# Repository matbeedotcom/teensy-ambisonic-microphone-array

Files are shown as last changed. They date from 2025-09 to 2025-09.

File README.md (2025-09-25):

# Teensy Ambisonic Microphone Array

A real-time 3D audio capture and direction-of-arrival (DOA) system using Teensy 4.1 and MEMS microphones.

## Overview

This project implements an 8-channel tetrahedral microphone array for spatial audio applications. Four INMP441 digital MEMS microphones capture sound from all directions, enabling real-time sound source localization with visual feedback.

### Key Features

- **8-channel audio capture** via dual Teensy 4.1 boards (master/slave configuration)
- **Real-time DOA estimation** using GCC-PHAT and SRP-PHAT algorithms
- **Sound classification** to filter and track specific audio types (voice, music, claps)
- **Live visualization** with 2D/3D directional plots and channel monitoring
- **3D-printable frame** with integrated wire management

## System Architecture

```
┌─────────────┐     I2S      ┌──────────────┐     USB Audio    ┌──────────────┐
│ 4x INMP441  ├─────────────►│ Master Teensy├────────────────►│              │
│ Microphones │              │     4.1      │                  │   Host PC    │
└─────────────┘              └──────┬───────┘                  │   (Python)   │
                                     │ TDM                      │              │
┌─────────────┐     I2S      ┌──────┴───────┐                  │ ┌──────────┐ │
│ 4x INMP441  ├─────────────►│ Slave Teensy │                  │ │   DOA    │ │
│ Microphones │              │     4.1      │                  │ │Processing│ │
└─────────────┘              └──────────────┘                  │ └──────────┘ │
                                                                └──────────────┘
```

## Hardware Requirements

- 2× Teensy 4.1 boards
- 8× INMP441 I2S MEMS microphone breakout boards
- 3D printer for tetrahedral frame (70.7mm edge length)
- Wire for I2S and TDM connections
- USB cables for power and data

## Quick Start

### 1. Assemble Hardware

Print the tetrahedral frame and mount microphones:
```bash
cd mechanical
python generate_stl.py  # Creates STL files for 3D printing
```

Follow the [assembly guide](mechanical/assembly_instructions.md) for wiring details.

### 2. Flash Firmware

Upload firmware to both Teensy boards:
- **Master**: `teensy_src/teensy_ambisonic_microphone.ino`
- **Slave**: `teensy_src/slave.ino`

Note: Requires [Teensyduino](https://www.pjrc.com/teensy/teensyduino.html) with USB descriptor patches from `teensy_src/patches/`.

### 3. Install Host Software

```bash
cd host_src
pip install -r requirements.txt
```

### 4. Run DOA Visualization

```bash
python doa_visualizer.py
```

Click "Start" to begin real-time sound source tracking.

## Features in Detail

### Direction of Arrival Algorithms

- **GCC-PHAT**: Fast cross-correlation for time-delay estimation
- **SRP-PHAT**: Robust beamforming-based localization
- **Least-Squares**: Traditional triangulation from time differences

### Sound Classification

Automatically identifies and filters:
- Human voice
- Music
- Claps/transients
- Whistles
- Background noise

### Array Geometry

Regular tetrahedron configuration:
- 43.3mm radius (center to vertex)
- 109.5° angular separation between microphones
- Omnidirectional coverage with minimal blind spots

## Project Structure

```
teensy_ambisonic_microphone/
├── teensy_src/        # Teensy firmware (master/slave)
├── host_src/          # Python DOA processing and visualization
├── mechanical/        # 3D-printable frame design (OpenSCAD)
└── pcb/              # KiCad PCB designs
```

## Performance

- **Sample rate**: 44.1 kHz
- **Latency**: ~23ms (1024 sample blocks)
- **Angular resolution**: 5° grid spacing
- **Update rate**: 20 Hz visualization
- **Maximum trackable distance**: Limited by SNR, typically 3-5 meters indoors

## Applications

- Acoustic scene analysis
- Smart home voice control
- Robotics navigation
- Virtual reality audio
- Acoustic research
- Educational demonstrations

## Contributing

Contributions welcome! Areas of interest:
- Multi-source tracking
- Beamforming implementation
- Raspberry Pi host support
- ROS integration

## License

MIT License - See LICENSE file for details

## Acknowledgments

Built with:
- [Teensy Audio Library](https://www.pjrc.com/teensy/td_libs_Audio.html)
- [INMP441 MEMS Microphones](https://invensense.tdk.com/products/digital/inmp441/)
- Scientific Python stack (NumPy, SciPy, Matplotlib)

## Resources

- [Direction of Arrival Estimation](https://en.wikipedia.org/wiki/Direction_of_arrival)
- [Ambisonic Audio](https://en.wikipedia.org/wiki/Ambisonics)
- [GCC-PHAT Algorithm](https://doi.org/10.1109/TASSP.1976.1162830)

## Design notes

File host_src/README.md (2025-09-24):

# Ambisonic Microphone DOA Processing

This PC application processes audio from the Teensy ambisonic microphone array to calculate and visualize sound source directions in real-time.

## Features

- **Real-time Audio Capture**: Captures multi-channel audio from Teensy USB Audio device
- **GCC-PHAT Processing**: Computes Time Difference of Arrival (TDOA) using Generalized Cross-Correlation with Phase Transform
- **DOA Estimation**: Two algorithms available:
  - **SRP-PHAT**: Steered Response Power with Phase Transform (robust in reverberant environments)
  - **Least-Squares**: Traditional triangulation method (faster computation)
- **Live Visualization**: 2D polar and 3D spherical plots showing sound source directions
- **Configurable Array Geometry**: JSON-based microphone position configuration

## Installation

1. Install Python dependencies:
```bash
pip install -r requirements.txt
```

2. Connect your Teensy ambisonic microphone array via USB

## Usage

### Quick Start
```bash
# Test audio capture
python audio_capture.py

# Test DOA processing
python doa_processing.py

# Launch visualization GUI
python doa_visualizer.py
```

### Configuration

Edit `array_geometry.json` to match your microphone array:

```json
{
  "name": "your_array_name",
  "description": "Array description",
  "positions": [
    [x1, y1, z1],
    [x2, y2, z2],
    [x3, y3, z3],
    [x4, y4, z4]
  ],
  "sample_rate": 44100,
  "speed_of_sound": 343.0
}
```

Position coordinates are in meters, relative to array center.

## File Structure

- `audio_capture.py` - USB audio interface and streaming
- `doa_processing.py` - GCC-PHAT and DOA algorithms
- `doa_visualizer.py` - Real-time visualization GUI
- `array_geometry.json` - Microphone array configuration
- `requirements.txt` - Python dependencies

## Algorithm Details

### GCC-PHAT (Generalized Cross-Correlation with Phase Transform)

1. **Windowing**: Apply Hann window to reduce spectral leakage
2. **FFT**: Compute frequency domain representations
3. **Cross-spectrum**: Calculate X₁(f) × X₂*(f) for each microphone pair
4. **PHAT Weighting**: Normalize by magnitude: C(f) / |C(f)|
5. **IFFT**: Convert back to time domain to get correlation function
6. **Peak Detection**: Find maximum within physical delay constraints

### SRP-PHAT (Steered Response Power)

1. Create spherical grid of candidate directions (5° resolution)
2. For each direction, compute expected delays between microphone pairs
3. Sample cross-correlation functions at expected delays
4. Sum contributions from all microphone pairs
5. Select direction with maximum summed response

### Least-Squares DOA

1. Extract TDOA estimates from GCC-PHAT peaks
2. Grid search over spherical directions
3. For each direction, compute expected TDOAs
4. Find direction minimizing squared error with measured TDOAs

## Performance Notes

- **Block Size**: 1024 samples provides ~23ms latency at 44.1kHz
- **Grid Resolution**: 5° spacing gives good accuracy/speed tradeoff
- **Confidence Filtering**: Helps reject spurious detections in noisy conditions
- **Memory Usage**: ~50MB typical for real-time processing

## Troubleshooting

### Audio Device Not Found
1. Check USB connection to Teensy
2. Verify Teensy appears as "Teensy Audio" or similar in device list
3. Run `audio_capture.py` to see available devices

### Poor DOA Accuracy
1. Verify microphone array geometry in `array_geometry.json`
2. Check for consistent channel mapping (clap test near each mic)
3. Adjust `speed_of_sound` for temperature: c ≈ 331 + 0.6 × T°C
4. Try larger block size (2048) in noisy environments

### High CPU Usage
1. Reduce spherical grid resolution (use 10° instead of 5°)
2. Increase block size to reduce processing rate
3. Use least-squares method instead of SRP-PHAT

## Hardware Requirements

- **Teensy 4.1** with 4-8 channel audio streaming
- **INMP441 I2S microphones** in tetrahedral or planar arrangement
- **USB connection** for audio streaming
- **PC** with Python 3.7+ and audio drivers

## Future Enhancements

- Multiple simultaneous source tracking
- Adaptive beamforming
- Noise suppression and source separation
- Integration with room correction
- Export to common audio formats

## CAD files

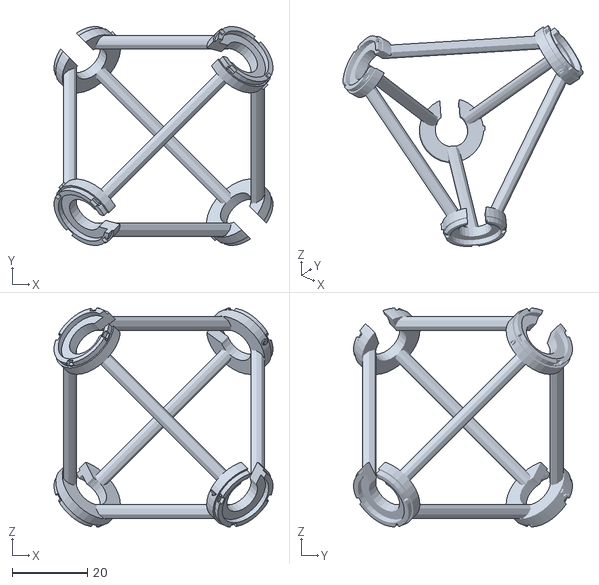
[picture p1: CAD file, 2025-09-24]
mechanical/tetrahedron_frame.stl
58.3 x 58.3 x 58.3

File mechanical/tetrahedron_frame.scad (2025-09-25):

/**
 * Tetrahedral Microphone Array Frame
 *
 * Designed for 4x INMP441 breakout boards (15mm diameter)
 * Regular tetrahedron with 50mm center-to-vertex distance
 *
 * IMPORTANT: Microphones are oriented OUTWARD from the center!
 * Each mic faces away from the tetrahedron center to capture
 * directional audio from all around the sphere.
 *
 * This gives proper ambisonic capture with sensitivity to:
 * - All horizontal directions (360° azimuth)
 * - Elevation angles from -90° to +90°
 *
 * Includes wire management and strain relief
 */

// Design parameters
vertex_distance = 25;           // Distance from center to vertex (25mm = 50mm spacing)
mic_board_diameter = 15;        // Microphone breakout board diameter
board_thickness = 1.6;          // PCB thickness
wire_diameter = 8;              // Wire bundle diameter
frame_thickness = 2;            // Frame rod thickness
mount_thickness = 3;            // Mounting pad thickness
mount_offset = -10.0;             // Distance from vertex to mounting pad (mm)
post_offset = 1.0;               // Distance from PCB edge to mounting posts (mm)
slot_rotations = [45, 90, 90, 45]; // Optimized angles for each vertex
clearance = 0.2;                // 3D printing clearance

// Calculated tetrahedron vertices (regular tetrahedron)
a = vertex_distance;
vertices = [
    [ a,  a,  a],    // Vertex 0
    [ a, -a, -a],    // Vertex 1
    [-a,  a, -a],    // Vertex 2
    [-a, -a,  a]     // Vertex 3
];

// Main assembly
module tetrahedron_frame() {
    difference() {
        union() {
            // Frame structure
            tetrahedron_edges();

            // Microphone mounting points (positioned closer to connect with frame)
            for (i = [0:3]) {
                // Calculate outward normal vector for this vertex
                normal = vertices[i] / norm(vertices[i]);
                // Position mounting pad using constant offset
                mount_position = vertices[i] + normal * mount_offset;

                translate(mount_position) {
                    // Rotate mounting surface to face outward
                    rotate([0, atan2(sqrt(normal.x*normal.x + normal.y*normal.y), normal.z), atan2(normal.y, normal.x)]) {
                        microphone_mount(i);  // Pass vertex index
                    }
                }
            }
        }

        // Wire channels through frame
        wire_channels();

        // Mounting holes for microphones (positioned closer to match mounting pad)
        for (i = [0:3]) {
            // Calculate outward normal vector for this vertex
            normal = vertices[i] / norm(vertices[i]);
            // Position mounting holes using constant offset
            mount_position = vertices[i] + normal * mount_offset;
            translate(mount_position) {
                // Rotate mounting holes to match outward orientation
                rotate([0, atan2(sqrt(normal.x*normal.x + normal.y*normal.y), normal.z), atan2(normal.y, normal.x)]) {
                    microphone_mounting_holes();
                }
            }
        }
    }

    // Labels embedded on the outside of mounting pad cylinders
    for (i = [0:3]) {
        // Calculate outward normal vector for this vertex
        normal = vertices[i] / norm(vertices[i]);
        // Position label using constant offset
        mount_position = vertices[i] + normal * mount_offset;
        translate(mount_position) {
            // Rotate label to match outward orientation
            rotate([0, atan2(sqrt(normal.x*normal.x + normal.y*normal.y), normal.z), atan2(normal.y, normal.x)]) {
                // Position label on the outside surface of the mounting pad
                rotate([0, 0, 180]) {  // Rotate to opposite side from wire slot
                    translate([0, (mic_board_diameter + 5)/2, mount_thickness/2]) {
                        rotate([90, 0, 0]) {
                            linear_extrude(1) {
                                text(str(i), size=2, halign="center", valign="center", font="Arial:style=Bold");
                            }
                        }
                    }
                }
            }
        }
    }
}

// Tetrahedron edge structure
module tetrahedron_edges() {
    difference() {
        // Connect each vertex to every other vertex (full frame)
        union() {
            for (i = [0:3]) {
                for (j = [i+1:3]) {
                    hull() {
                        translate(vertices[i]) sphere(r=frame_thickness);
                        translate(vertices[j]) sphere(r=frame_thickness);
                    }
                }
            }
        }

        // Subtract mounting pad volumes and everything above them from frame
        for (i = [0:3]) {
            // Calculate outward normal vector for this vertex
            normal = vertices[i] / norm(vertices[i]);
            // Position where mounting pad will be
            mount_position = vertices[i] + normal * mount_offset;

            translate(mount_position) {
                // Rotate to match mounting pad orientation
                rotate([0, atan2(sqrt(normal.x*normal.x + normal.y*normal.y), normal.z), atan2(normal.y, normal.x)]) {
                    // Cut out volume for mounting pad and everything above it
                    cylinder(h=50, d=mic_board_diameter + 6, center=false, $fn=32);
                }
            }
        }
    }
}

// Microphone mounting pad - fixed to frame
module microphone_mount(vertex_index = 0) {
    difference() {
        union() {
            // Base mounting pad
            cylinder(h=mount_thickness, d=mic_board_diameter + 4, center=false, $fn=32);

            // Raised rim to hold PCB (1mm thick) with snap-fit
            translate([0, 0, mount_thickness]) {
                difference() {
                    cylinder(h=1.5, d=mic_board_diameter + 3, center=false, $fn=32);
                    translate([0, 0, -0.1]) {
                        cylinder(h=1.7, d=mic_board_diameter + clearance, center=false, $fn=32);
                    }
                }
            }

            // Press-fit posts for cap attachment (4 posts)
            for (angle = [0:90:270]) {
                rotate([0, 0, angle]) {
                    translate([mic_board_diameter/2 + post_offset, 0, mount_thickness]) {
                        // Posts that the cap will press onto
                        cylinder(h=2, d=2, center=false, $fn=12);
                    }
                }
            }
        }

        // Center hole (1cm diameter) - through entire mount
        translate([0, 0, -0.1]) {
            cylinder(h=mount_thickness + 2, d=10, center=false, $fn=24);
        }

        // Cable passthrough slot - positioned to avoid frame connections
        // Rotate the slot direction based on vertex to avoid frame edge interference
        rotate([0, 0, slot_rotations[vertex_index]]) {
            translate([0, (mic_board_diameter + 6)/4, mount_thickness/2]) {
                cube([6, (mic_board_diameter + 6)/2, mount_thickness + 4], center=true);
            }
        }
    }
}

// This module is no longer needed - holes are integrated into microphone_mount()
module microphone_mounting_holes() {
    // No additional holes needed - everything is handled in microphone_mount()
}

// Central hub for wire management
module central_hub() {
    sphere(r=8, $fn=32);
}

// Wire routing channels
module wire_channels() {
    // Channels from each vertex to center
    for (i = [0:3]) {
        hull() {
            translate(vertices[i]) {
                cylinder(h=mount_thickness + 1, d=wire_diameter + 1, center=true, $fn=16);
            }
            cylinder(h=6, d=wire_diameter + 1, center=true, $fn=16);
        }
    }

    // Central wire exit hole
    cylinder(h=20, d=8, center=true, $fn=16);
}

// Removed strain relief clips - not needed

// Assembly instructions marker
module assembly_marker(vertex_num) {
    translate([0, 0, mount_thickness + 0.1]) {
        color("red") {
            linear_extrude(0.3) {
                difference() {
                    circle(d=4, $fn=16);
                    text(str(vertex_num), size=2, halign="center", valign="center");
                }
            }
        }
    }
}

// Press-fit cap for securing PCB to mounting pad
module mounting_cap() {
    difference() {
        union() {
            // Main cap body
            cylinder(h=1, d=mic_board_diameter + 2, center=false, $fn=32);

            // Raised edge to hold PCB down
            translate([0, 0, 1]) {
                difference() {
                    cylinder(h=0.5, d=mic_board_diameter + 2, center=false, $fn=32);
                    translate([0, 0, -0.1]) {
                        cylinder(h=0.7, d=mic_board_diameter - 2, center=false, $fn=32);
                    }
                }
            }
        }
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

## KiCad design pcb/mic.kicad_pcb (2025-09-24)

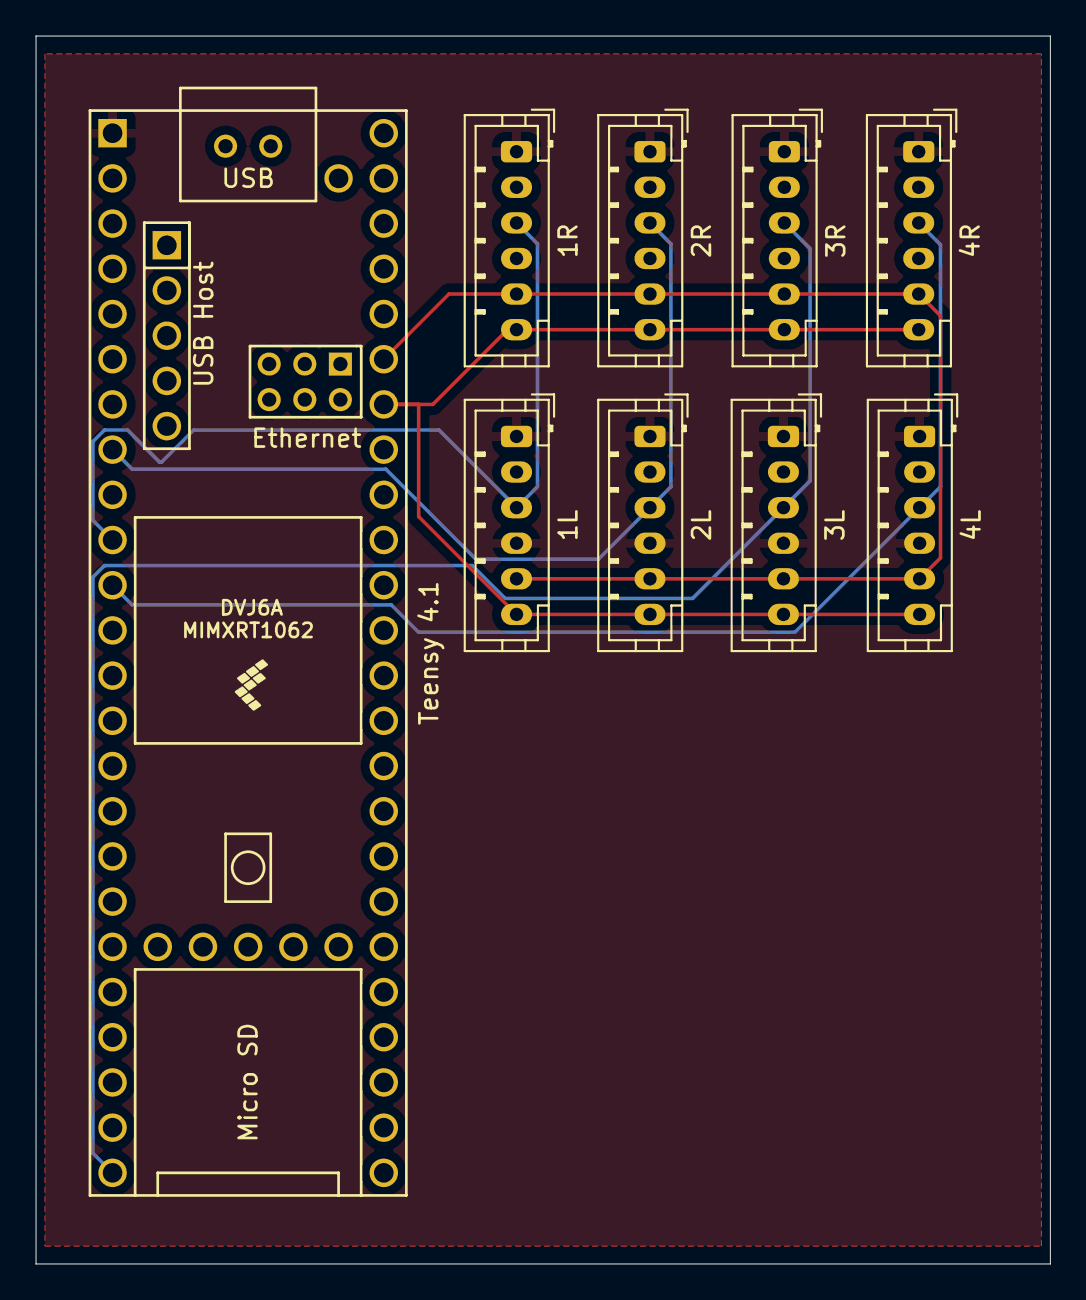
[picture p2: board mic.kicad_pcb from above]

Board: 4 copper layers, 57.0 x 69.0 mm, 9 parts (0 on the bottom side), 8 nets.

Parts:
1L, 2L, 3L, 4L: LeftMic; JST_PH_B6B-PH-K_1x06_P2.00mm_Vertical
1R, 2R, 3R, 4R: RightMic; JST_PH_B6B-PH-K_1x06_P2.00mm_Vertical
Teensy 4.1: Teensy4.1; Teensy41

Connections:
+3.3V: 1L.2, 1R.2, 1R.4, 2L.2, 2R.2, 2R.4, 3L.2, 3R.2, 3R.4, 4L.2, 4R.2, 4R.4, Teensy 4.1.46 (3V3)
BCLK1: 1L.5, 1R.5, 2L.5, 2R.5, 3L.5, 3R.5, 4L.5, 4R.5, Teensy 4.1.43 (21_A7_RX5_BCLK1)
GND: 1L.1, 1L.4, 1R.1, 2L.1, 2L.4, 2R.1, 3L.1, 3L.4, 3R.1, 4L.1, 4L.4, 4R.1, Teensy 4.1.1 (GND)
LRCLK1: 1L.6, 1R.6, 2L.6, 2R.6, 3L.6, 3R.6, 4L.6, 4R.6, Teensy 4.1.42 (20_A6_TX5_LRCLK1)
SAI1_RXD0: 1L.3, 1R.3, Teensy 4.1.10 (8_TX2_IN1)
SAI1_RXD1: 2L.3, 2R.3, Teensy 4.1.8 (6_OUT1D)
SAI1_RXD2: 3L.3, 3R.3, Teensy 4.1.24 (32_OUT1B)
SAI1_RXD3: 4L.3, 4R.3, Teensy 4.1.11 (9_OUT1C)

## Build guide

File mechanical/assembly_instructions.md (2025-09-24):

# Tetrahedral Microphone Array Assembly Instructions

## Overview
This guide covers assembly of the 3D printed tetrahedral frame for your 4-microphone ambisonic array.

⚠️ **CRITICAL**: Microphones must face **OUTWARD** from the center for proper directional audio capture!

## Parts Required

### 3D Printed Components
- [x] 1x Tetrahedral frame (`tetrahedron_frame.stl`)
- [x] 4x PCB adapter rings with twist-lock tabs (included in print)
- [x] 4x Strain relief clips (included in print)
- [x] 1x Wire management clip (included in print)

### Electronic Components
- [x] 4x INMP441 I2S microphone breakout boards (15mm diameter, 1mm thick)
- [x] 4x sets of I2S wires (5-wire: VDD, GND, SCK, WS, SD)
- [x] Small amount of double-sided tape or adhesive (optional)

### Tools Needed
- Wire strippers
- Soldering iron & solder
- Heat shrink tubing (optional)
- Small drill bit (2-3mm) for cable routing if needed

## Assembly Steps

### Step 1: 3D Print Preparation
1. **Print Settings**:
   - Layer Height: 0.2mm
   - Infill: 20-30%
   - No supports needed (designed support-free)
   - Print with central hub at bottom

2. **Post-Processing**:
   - Remove any support material or brim
   - Test-fit microphone boards in mounting holes
   - Clean mounting holes with small drill bit if needed

### Step 2: Microphone Orientation Check

**CRITICAL**: Each microphone must face **OUTWARD** from the tetrahedron center.

The INMP441 microphone element (small black square) should point:
- **Mic 0**: Up-Right-Forward direction
- **Mic 1**: Up-Left-Back direction
- **Mic 2**: Down-Right-Back direction
- **Mic 3**: Down-Left-Forward direction

### Step 3: Wire Preparation

For each microphone, prepare a 4-wire cable (~20cm length):
- **Red**: VDD (3.3V)
- **Black**: GND
- **Blue**: SCK (Serial Clock)
- **Green**: WS (Word Select/LRCLK)
- **Yellow**: SD (Serial Data)

1. Strip wire ends (~3mm)
2. Pre-tin wire ends with solder
3. Add strain relief clips to wire bundles

### Step 4: Microphone Mounting

For each of the 4 vertex positions:

1. **Orient the microphone correctly**:
   - Place breakout board on mounting pad
   - Ensure microphone element faces OUTWARD from center
   - The mic should point away from the central hub

2. **Solder connections**:
   - Solder 5-wire bundle to breakout board
   - Use heat shrink or tape for strain relief

3. **Secure with screws**:
   - Insert M2 screws through mounting holes
   - Tighten gently (don't over-torque plastic)

4. **Route wires**:
   - Thread wire bundle through vertex channel toward center
   - Leave enough slack for movement

### Step 5: Wire Management

1. **Route all wires to central hub**
2. **Group by function**:
   - All VDD wires → single power connection
   - All GND wires → single ground connection
   - Each SCK/WS/SD → separate I2S connections

3. **Use wire management clip** to organize cable bundle
4. **Add strain relief** at central hub exit

### Step 6: Testing & Calibration

1. **Visual inspection**:
   - All 4 microphones face outward ✓
   - No loose connections ✓
   - Wires properly managed ✓

2. **Electrical test**:
   - Check continuity of all connections
   - Verify no shorts between power rails

3. **Functional test**:
   - Connect to Teensy and run audio capture
   - Clap near each microphone to verify channel mapping
   - Use DOA visualizer to check directional response

## Microphone Channel Mapping

Based on your array geometry configuration:

| Position | Vertex | Direction Vector | I2S Connection |
|---|---|---|---|
| Mic 0 | (+,+,+)| Up-Right-Forward | SAI1_RXD0 Left |
| Mic 1 | (+,-,-)| Up-Left-Back | SAI1_RXD0 Right|
| Mic 2 | (-,+,-)| Down-Right-Back  | SAI1_RXD1 Left |
| Mic 3 | (-,-,+)| Down-Left-Forward| SAI1_RXD1 Right|

## Troubleshooting

### Poor Directional Response
- **Check**: Are all mics facing outward?
- **Fix**: Remount any inward-facing microphones

### Noisy Audio
- **Check**: Wire shielding and grounding
- **Fix**: Add twisted pair wiring, star ground connection

### Inconsistent Channel Levels
- **Check**: Loose connections, damaged microphones
- **Fix**: Resolder connections, replace faulty mics

### Mechanical Issues
- **Check**: 3D print quality, screw tightness
- **Fix**: Reprint damaged parts, adjust mounting

## Mounting the Complete Array

The assembled array can be mounted using:
1. **Tripod mount**: Add 1/4"-20 threaded insert to central hub
2. **Ceiling mount**: Suspend from central point with wire/chain
3. **Desktop stand**: Create weighted base with central mount point

## Final Notes

- Keep the array away from reflective surfaces during testing
- The frame is designed to minimize acoustic shadowing
- Label each microphone channel for easy identification
- Store in protective case when not in use

Good luck with your ambisonic array build! 🎤🔊

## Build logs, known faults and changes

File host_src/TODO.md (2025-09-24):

Awesome—here’s a tight, technical blueprint to get **Stage A (4-mic GCC-PHAT DOA)** working end-to-end with your Teensy and Windows host.

---

# 1) Hardware & wiring (4 mics)

Use **two I²S stereo pairs** on **SAI1**:

* Shared to all 4 mics: **BCLK = pin 21**, **LRCLK/WS = pin 20**, **3V3**, **GND** (0.1 µF at each mic).
* **Pair A** → **SAI1\_RXD0 (pin 8)**

  * Mic A-L: L/R → **GND** (Left slot), SD tied to RXD0
  * Mic A-R: L/R → **3V3** (Right slot), SD tied to RXD0
* **Pair B** → **SAI1\_RXD1 (pin 6)**

  * Mic B-L: L/R → **GND** (Left slot), SD tied to RXD1
  * Mic B-R: L/R → **3V3** (Right slot), SD tied to RXD1

Keep BCLK/LRCLK short & clean; series 22–33 Ω at the Teensy end are nice to have if wires are long.

---

# 2) Teensy firmware (capture 4 channels → USB)

* **USB Type:** Audio (16-bit, 44.1 kHz default)
* **Input:** `AudioInputI2SQuad` (uses SAI1\_RXD0 + RXD1 → 4 channels)
* **Output:** `AudioOutputUSB` (exposes 4 inputs to host)
* **Descriptor:** you already patched 4-in; if not, use the 4-ch descriptor we made.

Minimal sketch:

```cpp
#include <Audio.h>
#include <Arduino.h>

AudioInputI2SQuad i2sQuadIn;  // 4-ch on SAI1 RXD0/RXD1
AudioOutputUSB    usb_out;

// Route 4 ADC lanes -> USB in ch0..3
AudioConnection c0(i2sQuadIn, 0, usb_out, 0); // A-L
AudioConnection c1(i2sQuadIn, 1, usb_out, 1); // A-R
AudioConnection c2(i2sQuadIn, 2, usb_out, 2); // B-L
AudioConnection c3(i2sQuadIn, 3, usb_out, 3); // B-R

void setup() { AudioMemory(120); }
void loop() {}
```

**Channel order sanity:** clap near each mic and watch which host channel spikes (label them now).

---

# 3) Array geometry (choose one)

* **Tetrahedron (recommended for 3D DOA):** vertices of a regular tetra scaled to your shell. Example (meters, centered at origin):

  ```
  p0 = (  a,  a,  a)
  p1 = (  a, -a, -a)
  p2 = (-a,  a, -a)
  p3 = (-a, -a,  a)
  a = 0.025  // ~50 mm spacing tip-to-origin
  ```
* **Planar square (good for 2D azimuth):** 4 corners in one plane; you’ll estimate azimuth only (elevation ambiguous).

Store `P = [p0..p3]` in a JSON the host loads.

---

# 4) Host pipeline (GCC-PHAT → DOA)

We’ll run **block-wise**, e.g. **N=1024** samples (@44.1 kHz → ≈23 ms latency). Steps:

### (a) Read multichannel block

Get 4-ch interleaved **int16** from the Teensy USB device.

### (b) Preprocess

* Convert to float, apply Hann window.
* Optional 1st-order HPF (30–50 Hz) to remove DC/rumble.

### (c) GCC-PHAT (pairwise cross-correlation)

For each pair (i,j), compute time delay of arrival (TDOA) $\hat{\tau}_{ij}$:

1. FFT: $X_i = \mathrm{FFT}(x_i)$, $X_j = \mathrm{FFT}(x_j)$
2. Cross-spectrum: $C_{ij} = X_i \cdot \overline{X_j}$
3. PHAT weight: $C_{ij} \leftarrow C_{ij} / (|C_{ij}|+\epsilon)$
4. IFFT: $r_{ij} = \mathrm{IFFT}(C_{ij})$
5. **Peak** at allowed lags: $\hat{\tau}_{ij} = \arg\max_{|\tau| \le \tau_\text{max}} r_{ij}(\tau)$

Lag bound: $\tau_\text{max} = \frac{d_\text{max}}{c}$, $c \approx 343\,\mathrm{m/s}$, $d_\text{max}$ = max mic spacing (e.g., 0.07 m → ≈0.2 ms → ±9 samples @44.1 k).

### (d) DOA solve

#### 2D (square, azimuth only)

* Assume source on the array plane (z=0); unit direction $\mathbf{s}=[\cos\theta, \sin\theta, 0]$.
* For each pair, model $\tau_{ij} = \frac{1}{c}\,\mathbf{s}\cdot(\mathbf{p}_i - \mathbf{p}_j)$.
* **Grid search** θ ∈ \[−180°,180°], pick θ maximizing consistency with $\hat{\tau}_{ij}$ (least-squares or correlation).

#### 3D (tetra, full DOA)

Two robust approaches:

* **Least-squares on sphere:** find unit $\mathbf{s}$ minimizing
  $\sum_{i<j} \left(\hat{\tau}_{ij} - \frac{1}{c}\,\mathbf{s}\cdot(\mathbf{p}_i-\mathbf{p}_j)\right)^2$ with $\|\mathbf{s}\|=1$. Solve by coarse **spherical grid** (e.g., 5°) then local refine (Gauss-Newton) with unit-norm constraint.

* **SRP-PHAT (steered response):** create a direction grid on the sphere (3–5°). For each direction $\mathbf{s}$, convert to expected **sample delays** $d_{ij} = \mathrm{round}\big((f_s/c)\,\mathbf{s}\cdot(\mathbf{p}_i-\mathbf{p}_j)\big)$. **Sum** the cross-correlations at those delays over all pairs; pick the max.

For 4 mics, both are fast and accurate. SRP-PHAT is very robust in reverb; LS is lighter.

---

# 5) Reference host code (Python, minimal SRP-PHAT)

Below is a compact script outline (uses `sounddevice`, `numpy`). It:

* captures 4-ch blocks from Teensy,
* computes **PHAT-weighted cross-correlations**,
* evaluates a **3D grid**,
* prints azimuth/elevation.

```python
import numpy as np, sounddevice as sd
from numpy.fft import rfft, irfft
from math import pi

# -------- Config --------
fs = 44100
N  = 1024                      # block size
eps = 1e-12
c   = 343.0

# Mic positions (meters): regular tetra around origin
a = 0.025
P = np.array([[ a,  a,  a],
              [ a, -a, -a],
              [-a,  a, -a],
              [-a, -a,  a]], dtype=np.float64)
pairs = [(i,j) for i in range(4) for j in range(i+1,4)]

# Precompute a spherical grid (5°)
def sphere_grid(step_deg=5):
    dirs=[]
    for el in np.radians(np.arange(-85, 86, step_deg)):   # avoid exact poles in coarse grid
        for az in np.radians(np.arange(-180, 180, step_deg)):
            ce, se = np.cos(el), np.sin(el)
            ca, sa = np.cos(az), np.sin(az)
            dirs.append([ce*ca, ce*sa, se])
    return np.array(dirs, dtype=np.float64)
G = sphere_grid(5)             # (Ng,3)
Ng = G.shape[0]
# Expected sample delays per pair and grid dir
D = {}
scale = fs / c
for (i,j) in pairs:
    v = (P[i]-P[j]) @ G.T      # (Ng,)
    D[(i,j)] = np.rint(scale * v).astype(int)

# Choose Teensy device
dev = None
for i,d in enumerate(sd.query_devices()):
    if 'teensy' in d['name'].lower() and d['max_input_channels']>=4:
        dev=i; break
assert dev is not None, "Teensy 4-ch device not found"

# -------- Streaming loop --------
with sd.InputStream(device=dev, channels=4, samplerate=fs, blocksize=N, dtype='int16') as st:
    win = np.hanning(N).astype(np.float64)
    while True:
        x, _ = st.read(N)                 # shape (N,4), int16
        X = (x.astype(np.float64) * win[:,None])  # window & float
        # FFT along time
        XF = rfft(X, axis=0)              # (Nf, 4)

        # Pairwise PHAT cross-corr via IFFT
        score = np.zeros(Ng, dtype=np.float64)
        for (i,j) in pairs:
            Cij = XF[:,i] * np.conj(XF[:,j])
            Cij /= (np.abs(Cij) + eps)
            rij = irfft(Cij)              # circular corr, length N
            # Use a small lag window around 0 (based on array span)
            # Here: +/- 10 samples
            # Accumulate SRP by sampling rij at expected delays for each direction
            di = D[(i,j)]
            # wrap indices to [0,N)
            idx = (di % N)
            score += rij[idx]

        k = int(np.argmax(score))
        s = G[k]                           # unit DOA vector
        az = np.degrees(np.arctan2(s[1], s[0]))
        el = np.degrees(np.arcsin(s[2]))
        print(f"DOA ~ az {az:6.1f}°, el {el:5.1f}° (conf {score[k]:.2f})")
```

**Notes:**

* For a small array (≤10 cm), **±10–15 samples** is a safe lag bound—tighten for speed/robustness.
* You can refine DOA by doing a **local fine search** (1–2° step) around the coarse max.

---

# 6) Calibration & checks

* **Channel map:** do a single-mic tap test (or a beeper) near each sensor to confirm labels.
* **Geometry scale:** if DOA biases, your mic spacing may be off—measure and update `P`.
* **Speed of sound:** set `c` from ambient temp (e.g., $c \approx 331 + 0.6T_{°C}$).

---

# 7) Performance tips

* If the GCC peaks look broad/noisy, bump to **N=2048** (≈46 ms).
* **16-bit** is fine for DOA—phase dominates.
* For reverberant rooms, SRP-PHAT (as coded) outperforms simple TDOA triangulation.

---

## Milestone checklist (Stage A)

1. Teensy enumerates as **4-in**; Audacity/ffmpeg sees 4 channels.
2. Python script prints **sensible az/el** while you move a clap/snap around.
3. Save a few WAVs for offline analysis & parameter tuning.

When Stage A feels solid, we’ll bump to **8** and **12** with the same host code—just update `P` and the device’s channel count.

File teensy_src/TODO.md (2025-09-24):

Here’s the practical, nuts-and-bolts way to make **Teensy B** a **clock-slave** that **packs \~8 input channels into a single TDM stream** and sends that to **Teensy A**.

---

# 1) Wiring (one clock domain from A)

**A (master)** → **B (slave)**

* **BCLK**: A pin **21** → B pin **21**
* **LRCLK/FS**: A pin **20** → B pin **20**
* **GND**: common ground
* **TDM data B→A**: B pin **7** (`SAI1_TXD0`) → A pin **8** (`SAI1_RXD0`)

**B’s microphones** (unchanged):

* All INMP441 mics on B still use **BCLK=21** and **LRCLK=20** (now driven by A), and their **SD** lines go to B’s **RXDx** pins (e.g., SAI1\_RXD0/1/2/3 & SAI2\_RXD0/1).

---

# 2) What the firmware needs to do on Teensy B

### Inputs (mic capture) — run as **slave**

* Use the **slave** variants for I²S where available:

  * `AudioInputI2Sslave` (for a stereo pair on SAI2, etc.)
* For `AudioInputI2SQuad` (SAI1 RXD0+RXD1) there isn’t an official slave object; you either:

  * use two `AudioInputI2Sslave` objects on the lanes you’re using, **or**
  * drop in a tiny **Quad-Slave** class (I can supply this if you want to keep quad).

Either way, the key is: **B never drives clocks**; it just samples on A’s BCLK/LRCLK.

### Output (TDM transmit) — run TDM **TX as slave**

* Stock `AudioOutputTDM` configures SAI **as master**.
* For your topology, you want a **TDM TX “slave”**: SAI1 TX uses **external BCLK/LRCLK** from A and only drives **TXD0** (pin 7).

This is a very small init tweak to the TDM TX config:

* **Bit-clock direction** = **external** (SAI uses incoming BCLK)
* **Frame-sync direction** = **external** (uses incoming LRCLK/FS)
* **Frame size** = **16 slots** (we’ll use 8 of them and zero the rest)
* **Slot width** = **32 bits** (common & simple; matches Teensy’s TDM class)
* **DMA** fills the 16 slots each audio block; your 8 channels map to **slots 0–7**

---

# 3) Channel plan (8-out TDM16)

* Map your 8 captured mic channels to **TDM slots 0..7**
* Write **zeros** into slots **8..15**
* On Teensy A, use `AudioInputTDM` and read channels 0..7 (ignore 8..15)

---

# 4) Minimal code shape on Teensy B

Below is the **shape** (not the whole Teensy Audio class), so you see what changes. If you like, I can drop a ready-to-compile `AudioOutputTDM_Slave.cpp/.h` next.

```cpp
// Teensy B (slave): capture 8 mics, pack into TDM16 TX (slave), send to A

#include <Audio.h>
#include <Arduino.h>

// ---- inputs (examples) ----
// SAI1 lanes (quad) -> if you have a Quad-Slave class, use it; otherwise 2x I2Sslave
AudioInputI2Sslave i2s1_lane0; // e.g., RXD0 (Left/Right)
AudioInputI2Sslave i2s1_lane1; // e.g., RXD1 (Left/Right)

// SAI2 lane (extra stereo), optional
AudioInputI2Sslave i2s2_lane0;

// ---- TDM slave TX (custom object; uses external BCLK/LRCLK on pins 21/20) ----
AudioOutputTDM_Slave tdmTX;  // drives SAI1_TXD0 (pin 7), 16 slots/frame

// Connect 8 channels into TDM slots 0..7
// (Each AudioOutputTDM* exposes 16 inputs, like the stock TDM object.)
AudioConnection c0(i2s1_lane0, 0, tdmTX, 0);  // ch0 -> slot0
AudioConnection c1(i2s1_lane0, 1, tdmTX, 1);  // ch1 -> slot1
AudioConnection c2(i2s1_lane1, 0, tdmTX, 2);  // ch2 -> slot2
AudioConnection c3(i2s1_lane1, 1, tdmTX, 3);  // ch3 -> slot3
AudioConnection c4(i2s2_lane0, 0, tdmTX, 4);  // ch4 -> slot4
AudioConnection c5(i2s2_lane0, 1, tdmTX, 5);  // ch5 -> slot5
// Add two more inputs as needed:
AudioConnection c6(/* your next input */, 0, tdmTX, 6);
AudioConnection c7(/* your next input */, 0, tdmTX, 7);

void setup() {
  AudioMemory(200);

  // IMPORTANT: ensure B is not generating clocks
  // Using *slave* input objects does this for RX.
  // For TDM TX, our AudioOutputTDM_Slave init will configure SAI1 TX to use external BCLK/LRCLK.
}

void loop() {
  // Nothing; Audio library + DMA do the work
}
```

---

# 5) What the **TDM TX “slave” init** actually does (under the hood)

(For the i.MX RT1062 SAI, simplified; exact bit names vary slightly by header)

* **Select TDM mode / slot format**

  * `TCR4.FRSZ = 16-1`   // 16 slots per frame
  * `TCR4.SYWD = 32-1`   // 32-bit slot width
  * `TCR4.FSE = 1`       // frame sync early (aligns with standard TDM)
* **Use external clocks**

  * `TCR2.BCD = 0`       // Bit Clock Direction = external (slave)
  * `TCR4.FSD = 0`       // Frame Sync Direction = external (slave)
  * `TCR2.MSEL = 0`      // Bit-clock source = bus clock (ignored as slave)
* **Enable the transmitter on channel 0**

  * `TCR3.TCE = (1<<0)`  // Enable TX channel 0 (TXD0)
* **DMA**

  * Configure DMA to feed the TX FIFO every audio block; buffer layout = 16 interleaved slots × 32-bit words

That’s exactly what a small `AudioOutputTDM_Slave` class would set in its `begin()` before enabling `TCSR.TE`.

---

# 6) On Teensy A (the receiver)

* Keep A as **master** for clocks (default in Teensy Audio lib).
* Add `AudioInputTDM tdmIn;` and wire your 12 local + 8 remote channels as needed.
* A’s pin **8** is `SAI1_RXD0` → that’s the TDM data from B.
* USB on A advertises **(local + remote)** input channel count.

---

# 7) Signal-integrity tips

* Put **22–33 Ω** series resistors at **A’s** BCLK/LRCLK outputs (one per branch) if you have multiple long branches.
* Keep **B TXD0 → A RXD0** short and paired with **GND** (twisted pair / FFC with adjacent ground).
* Only **one** device (A) should ever drive BCLK/LRCLK.

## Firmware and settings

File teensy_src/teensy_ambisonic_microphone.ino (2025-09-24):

/* Teensy 4.1 Master - Local I2S + Remote TDM to 8-Channel USB
 *
 * This sketch receives:
 * - 4 local I2S microphone channels (SAI1 RX)
 * - 4 remote TDM channels from Teensy B slave (first 4 of 8 TDM slots)
 * - Routes all 8 channels to USB output
 *
 * Hardware connections for Teensy 4.1 Master (A):
 * Local microphones (unchanged):
 * - Pin 8 (GPIO_B1_00): SAI1_RXD0 - Local mic pair 1 (L1/R1)
 * - Pin 6 (GPIO_B0_10): SAI1_RXD1 - Local mic pair 2 (L2/R2)
 *
 * Clock generation (master):
 * - Pin 21 (GPIO_AD_B1_11): SAI1_BCLK - Bit clock (drives slave)
 * - Pin 20 (GPIO_AD_B1_10): SAI1_SYNC - Frame sync/LRCLK (drives slave)
 * - Pin 23 (GPIO_AD_B1_09): SAI1_MCLK - Master clock
 *
 * TDM data from Teensy B slave:
 * - Pin 8: SAI1_RXD0 - TDM data from slave (using slots 0-3 of 16)
 *
 * Note: Pin 8 serves dual purpose - local I2S RX and remote TDM RX
 */

 #include <Audio.h>
 #include <Wire.h>
 #include <SPI.h>
 
 // Create audio objects
 AudioInputI2SQuad    i2sQuadIn;      // 4-channel local I2S input using SAI1_RXD0 and RXD1
 AudioInputTDM        tdmIn;          // 16-channel TDM input (using channels 0-7 from slave)
 AudioOutputUSB       usbOut;         // 8-channel USB output to PC

 // Connect local I2S inputs to USB channels 0-3
 AudioConnection patchCord1(i2sQuadIn, 0, usbOut, 0);   // Local Ch0 (L1 from RXD0)
 AudioConnection patchCord2(i2sQuadIn, 1, usbOut, 1);   // Local Ch1 (R1 from RXD0)
 AudioConnection patchCord3(i2sQuadIn, 2, usbOut, 2);   // Local Ch2 (L2 from RXD1)
 AudioConnection patchCord4(i2sQuadIn, 3, usbOut, 3);   // Local Ch3 (R2 from RXD1)

 // Connect remote TDM inputs to USB channels 4-7 (first 4 of 8 TDM channels)
 AudioConnection patchCord5(tdmIn, 0, usbOut, 4);       // Remote Ch0 (440 Hz)
 AudioConnection patchCord6(tdmIn, 1, usbOut, 5);       // Remote Ch1 (523 Hz)
 AudioConnection patchCord7(tdmIn, 2, usbOut, 6);       // Remote Ch2 (659 Hz)
 AudioConnection patchCord8(tdmIn, 3, usbOut, 7);       // Remote Ch3 (784 Hz)

 // Monitor audio levels - local channels
 AudioAnalyzePeak     peakLocal[4];
 AudioConnection patchCord9(i2sQuadIn, 0, peakLocal[0], 0);
 AudioConnection patchCord10(i2sQuadIn, 1, peakLocal[1], 0);
 AudioConnection patchCord11(i2sQuadIn, 2, peakLocal[2], 0);
 AudioConnection patchCord12(i2sQuadIn, 3, peakLocal[3], 0);

 // Monitor audio levels - remote TDM channels (first 4)
 AudioAnalyzePeak     peakRemote[4];
 AudioConnection patchCord13(tdmIn, 0, peakRemote[0], 0);
 AudioConnection patchCord14(tdmIn, 1, peakRemote[1], 0);
 AudioConnection patchCord15(tdmIn, 2, peakRemote[2], 0);
 AudioConnection patchCord16(tdmIn, 3, peakRemote[3], 0);
 
 void setup() {
   Serial.begin(115200);

   // Audio initialization - increased memory for 12 channels
   AudioMemory(40);

   // Wait for serial monitor
   delay(1000);

   Serial.println("=============================================");
   Serial.println("Teensy 4.1 Master - 8-Channel USB Audio");
   Serial.println("=============================================");
   Serial.println();
   Serial.println("Local I2S microphones (4 channels):");
   Serial.println("  Pin 8:  SAI1_RXD0 (Local Pair 1 - L1/R1)");
   Serial.println("  Pin 6:  SAI1_RXD1 (Local Pair 2 - L2/R2)");
   Serial.println();
   Serial.println("Clock generation (master):");
   Serial.println("  Pin 21: SAI1_BCLK (drives slave)");
   Serial.println("  Pin 20: SAI1_SYNC/LRCLK (drives slave)");
   Serial.println("  Pin 23: SAI1_MCLK");
   Serial.println();
   Serial.println("TDM from Teensy B slave (first 4 of 8 channels):");
   Serial.println("  Pin 8:  SAI1_RXD0 (TDM data from slave)");
   Serial.println();
   Serial.println("USB Audio Channels:");
   Serial.println("  Ch 0-3: Local I2S microphones");
   Serial.println("  Ch 4-7: Remote TDM from slave");
   Serial.println("    Ch 4: 440 Hz (A4)");
   Serial.println("    Ch 5: 523 Hz (C5)");
   Serial.println("    Ch 6: 659 Hz (E5)");
   Serial.println("    Ch 7: 784 Hz (G5)");
   Serial.println();
   Serial.println("USB Audio: Should appear as 'Teensy Audio 8CH'");
   Serial.println("Starting 8-channel audio streaming...");
   Serial.println();
 }
 
 void loop() {
   // Print peak levels every 1000ms
   static elapsedMillis timeout = 0;

   if (timeout >= 1000) {
     timeout = 0;

     // Check if peak analyzers have data
     bool hasLocalData = true;
     bool hasRemoteData = true;

     for (int i = 0; i < 4; i++) {
       if (!peakLocal[i].available()) hasLocalData = false;
     }
     for (int i = 0; i < 4; i++) {
       if (!peakRemote[i].available()) hasRemoteData = false;
     }

     if (hasLocalData || hasRemoteData) {
       Serial.println("=== AUDIO LEVELS ===");

       // Local I2S channels
       if (hasLocalData) {
         Serial.print("Local I2S: ");
         for (int i = 0; i < 4; i++) {
           float level = peakLocal[i].read();
           Serial.print("Ch");
           Serial.print(i);
           Serial.print(":");
           printBarCompact(level);
           Serial.print(" ");
         }
         Serial.println();
       }

       // Remote TDM channels
       if (hasRemoteData) {
         Serial.print("Remote TDM: ");
         for (int i = 0; i < 4; i++) {
           float level = peakRemote[i].read();
           Serial.print("Ch");
           Serial.print(i + 4);  // USB channels 4-7
           Serial.print(":");
           printBarCompact(level);
           Serial.print(" ");
         }
         Serial.println();
       }
       Serial.println();
     }
   }

   // Print memory usage every 5 seconds
   static elapsedMillis statusTimeout = 0;
   if (statusTimeout >= 5000) {
     statusTimeout = 0;
     Serial.print("Audio memory: ");
     Serial.print(AudioMemoryUsage());
     Serial.print("/");
     Serial.print(AudioMemoryUsageMax());
     Serial.print("  CPU: ");
     Serial.print(AudioProcessorUsage());
     Serial.println("%");
     Serial.println();
   }
 }
 
 void printBar(float level) {
   Serial.print("[");
   int bars = level * 20;
   for (int i = 0; i < 20; i++) {
     if (i < bars) Serial.print("=");
     else Serial.print(" ");
   }
   Serial.print("]");
 }

 void printBarCompact(float level) {
   Serial.print("[");
   int bars = level * 8;  // Shorter bar for compact display
   for (int i = 0; i < 8; i++) {
     if (i < bars) Serial.print("=");
     else Serial.print(" ");
   }
   Serial.print("]");
 }

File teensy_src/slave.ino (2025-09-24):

/* Teensy B Slave - 8-Channel Sine Wave TDM Generator
 *
 * This sketch generates 8 sine waves at different frequencies and transmits
 * them via TDM slave mode to Teensy A master.
 *
 * Hardware connections for Teensy 4.1 Slave (B):
 * Clock inputs (from Master A):
 * - Pin 21: SAI1_RX_BCLK - Bit clock (from master)
 * - Pin 20: SAI1_RX_SYNC - Frame sync/LRCLK (from master)
 *
 * TDM output to Master A:
 * - Pin 7: SAI1_TXD0 - TDM data to master (8 channels in slots 0-7)
 *
 * Generated sine wave frequencies:
 * - Ch0: 440 Hz (A4)    - Ch4: 880 Hz (A5)
 * - Ch1: 523 Hz (C5)    - Ch5: 1047 Hz (C6)
 * - Ch2: 659 Hz (E5)    - Ch6: 1319 Hz (E6)
 * - Ch3: 784 Hz (G5)    - Ch7: 1568 Hz (G6)
 */

#include <Audio.h>
#include "AudioOutputTDM_Slave.h"

// Create 8 sine wave generators
AudioSynthWaveformSine sine1;
AudioSynthWaveformSine sine2;
AudioSynthWaveformSine sine3;
AudioSynthWaveformSine sine4;
AudioSynthWaveformSine sine5;
AudioSynthWaveformSine sine6;
AudioSynthWaveformSine sine7;
AudioSynthWaveformSine sine8;

// TDM slave output (uses external clocks from master)
AudioOutputTDM_Slave tdmTX;

// Connect sine generators to TDM output slots 0-7
AudioConnection c0(sine1, 0, tdmTX, 0);  // Ch0 -> TDM slot 0
AudioConnection c1(sine2, 0, tdmTX, 1);  // Ch1 -> TDM slot 1
AudioConnection c2(sine3, 0, tdmTX, 2);  // Ch2 -> TDM slot 2
AudioConnection c3(sine4, 0, tdmTX, 3);  // Ch3 -> TDM slot 3
AudioConnection c4(sine5, 0, tdmTX, 4);  // Ch4 -> TDM slot 4
AudioConnection c5(sine6, 0, tdmTX, 5);  // Ch5 -> TDM slot 5
AudioConnection c6(sine7, 0, tdmTX, 6);  // Ch6 -> TDM slot 6
AudioConnection c7(sine8, 0, tdmTX, 7);  // Ch7 -> TDM slot 7

void setup() {
  // Audio initialization
  AudioMemory(200);

  Serial.begin(115200);
  delay(1000);

  Serial.println("===============================================");
  Serial.println("Teensy 4.1 Slave - 8-Channel TDM Sine Generator");
  Serial.println("===============================================");
  Serial.println();
  Serial.println("Clock inputs (from Master A):");
  Serial.println("  Pin 21: SAI1_RX_BCLK (from master)");
  Serial.println("  Pin 20: SAI1_RX_SYNC (from master)");
  Serial.println();
  Serial.println("TDM output to Master A:");
  Serial.println("  Pin 7:  SAI1_TXD0 (TDM data to master)");
  Serial.println();

  // Configure sine wave generators
  sine1.frequency(440.0);   // A4
  sine1.amplitude(0.5);

  sine2.frequency(523.25);  // C5
  sine2.amplitude(0.5);

  sine3.frequency(659.25);  // E5
  sine3.amplitude(0.5);

  sine4.frequency(783.99);  // G5
  sine4.amplitude(0.5);

  sine5.frequency(880.0);   // A5
  sine5.amplitude(0.5);

  sine6.frequency(1046.5);  // C6
  sine6.amplitude(0.5);

  sine7.frequency(1318.5);  // E6
  sine7.amplitude(0.5);

  sine8.frequency(1568.0);  // G6
  sine8.amplitude(0.5);

  Serial.println("Generated TDM frequencies:");
  Serial.println("  TDM Slot 0: 440 Hz (A4)");
  Serial.println("  TDM Slot 1: 523 Hz (C5)");
  Serial.println("  TDM Slot 2: 659 Hz (E5)");
  Serial.println("  TDM Slot 3: 784 Hz (G5)");
  Serial.println("  TDM Slot 4: 880 Hz (A5)");
  Serial.println("  TDM Slot 5: 1047 Hz (C6)");
  Serial.println("  TDM Slot 6: 1319 Hz (E6)");
  Serial.println("  TDM Slot 7: 1568 Hz (G6)");
  Serial.println();
  Serial.println("TDM slave mode - waiting for master clocks...");
}

void loop() {
  // Print status every second
  delay(1000);
  Serial.print("CPU Usage: ");
  Serial.print(AudioProcessorUsage());
  Serial.print("%, Memory: ");
  Serial.print(AudioMemoryUsage());
  Serial.println(" blocks");
}

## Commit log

2025-09-24 Current state
2025-09-24 Current working state
    [mic-B_Cu.gbl, mic-B_Mask.gbs, mic-B_Paste.gbp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]
2025-09-25 Update array geometry and enhance DOA visualizer with sound classification features
    [tetrahedron_frame.scad]
2025-09-25 Add README.md for Teensy Ambisonic Microphone Array project with detailed overview, features, system architecture, hardware requirements, quick start guide, and applications
